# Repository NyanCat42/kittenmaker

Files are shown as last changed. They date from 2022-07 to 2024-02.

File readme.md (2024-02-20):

# kittenmaker

*kittenmaker* - an ESP32 based msla 3d printer

## YouTube video showcase 

Showcase video (https://www.youtube.com/watch?v=y37ohpzv8kI)

## Features 

- Web interface
- g-code parsing
- mid-print parameter updating
- magnetic, easily removable vat and printbed

kitten printed with the kittenmaker

## Hardware

- 3D printed body, vat, z-carriage

- 320x240 ili9341 TFT display (~0.14mm xy resolution)
- 28byj-48-5v stepper motor with uln2003 driver
- ESP32 development board
- 3W 405nm UV LED

- Various M3 and M2 hardware
- 3x7x3 bearings
- Body of a Bic crystal

## Software

Slicer [Chitubox 1.8 beta](https://www.chitubox.com/en/download/chitubox-free).

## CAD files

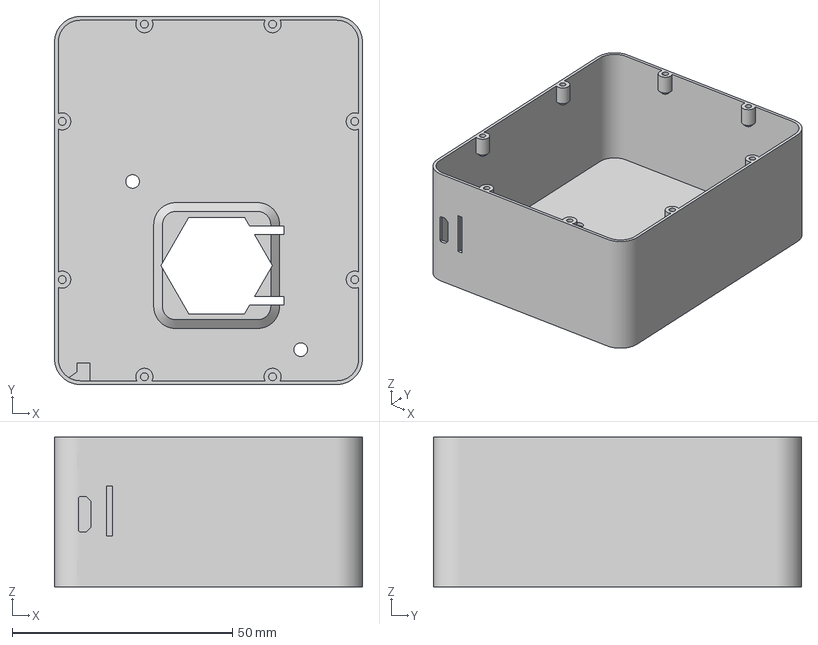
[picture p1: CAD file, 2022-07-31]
3d models/bottom (1).3mf
69.9 x 83.6 x 34.0 mm

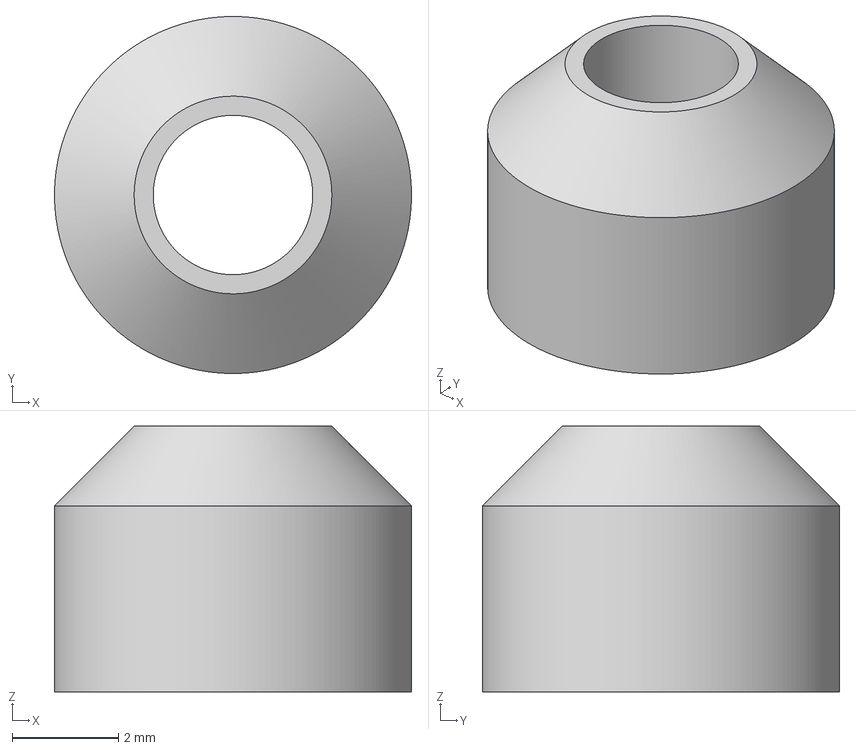
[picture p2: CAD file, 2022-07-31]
3d models/post.3mf
6.72 x 6.72 x 5.00 mm

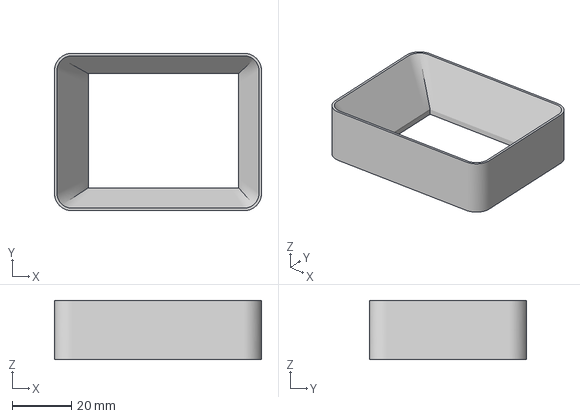
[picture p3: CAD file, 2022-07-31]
3d models/vat.3mf
69.9 x 53.2 x 20.0 mm

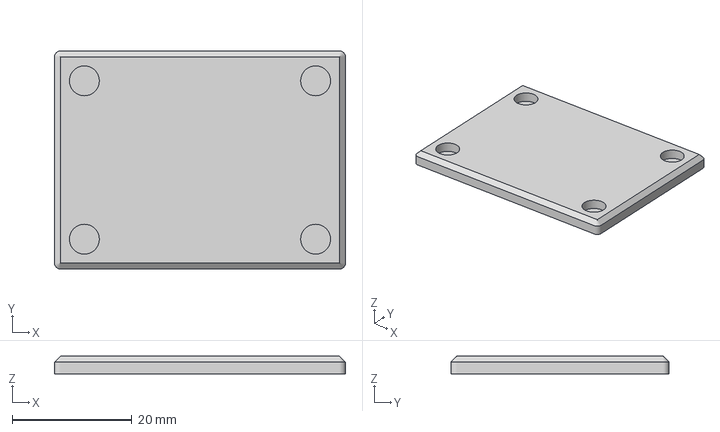
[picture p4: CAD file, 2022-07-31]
3d models/bed.3mf
48.7 x 36.5 x 3.00 mm

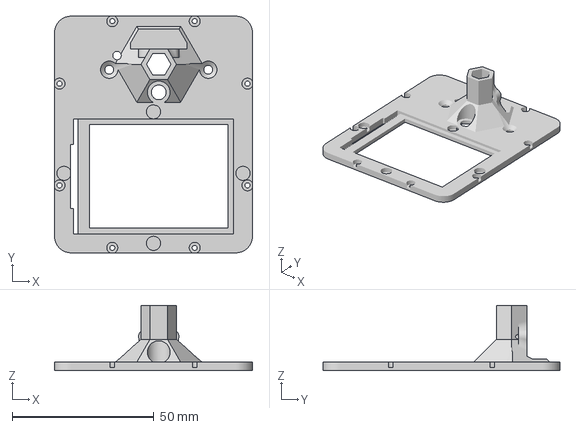
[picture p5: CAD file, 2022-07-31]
3d models/cover.3mf
69.9 x 83.6 x 23.0 mm

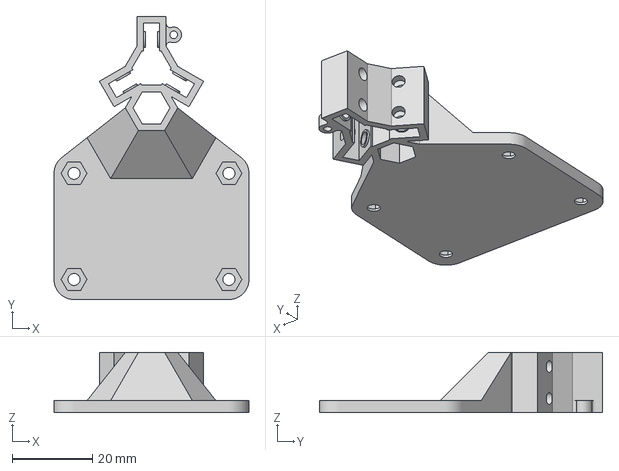
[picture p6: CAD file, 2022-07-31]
3d models/carriage.3mf
48.7 x 70.7 x 15.0 mm

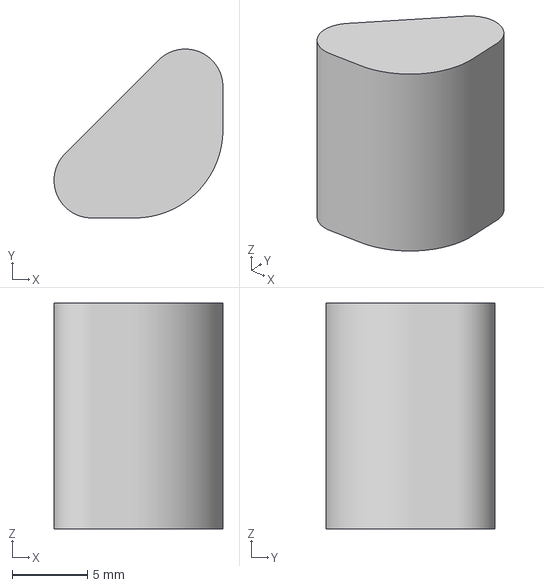
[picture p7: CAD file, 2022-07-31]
3d models/leg.3mf
11.2 x 11.2 x 15.0 mm

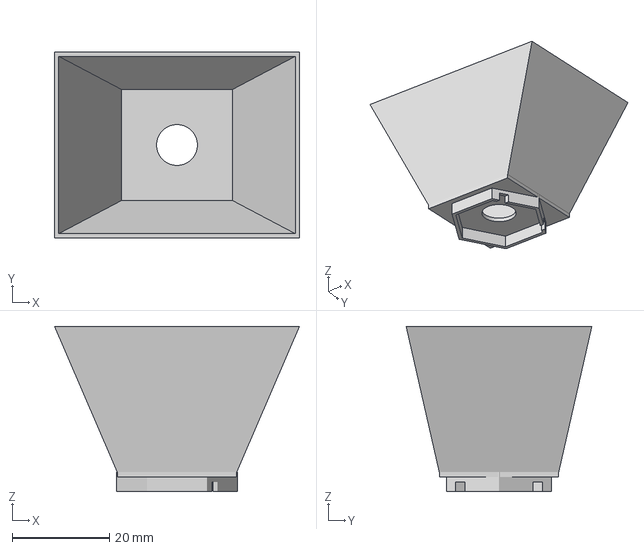
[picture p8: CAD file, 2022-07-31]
3d models/light_tunel.3mf
50.4 x 38.2 x 34.0 mm

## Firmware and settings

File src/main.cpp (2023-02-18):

#include <Arduino.h>
#include <WiFi.h>
#include <AsyncTCP.h>
#include <ESPAsyncWebServer.h>
#include "SPIFFS.h"
#include <Arduino_JSON.h>


#include <SPI.h>
#include <FS.h>
#include <SD.h>
#define FS_NO_GLOBALS

#include "setup_pins.h"
#include "wifi_ssid_password.h"

#include <GCodeParser.h>
GCodeParser GCode = GCodeParser();

#include <AccelStepper.h>
AccelStepper stepper1(8, stepper_pin_1, stepper_pin_3, stepper_pin_2, stepper_pin_4); // NOTE: The sequence 1-3-2-4 is required for proper sequencing of 28BYJ-48

#include <TFT_eSPI.h>
TFT_eSPI tft = TFT_eSPI();

#define USE_LINE_BUFFER
#include "support_functions.h"

int layerheight = 0;
int exposure_time = 0;
int bottom_exposure_time = 0;
int exposure_time_print;
int stepper_speed = 1000;
int stepper_accl = 1000;
int rise_height = 0;
int steps_per_layer;
float steps_per_um = 1.0189432; // or, to be more precise - 1.018943209876543209876543209876543209876543209876543209876543209876543209876543209876543209876543209876543209876543209876543209877
int layer = 1;
bool print_started = false;
bool calibrating = false;
bool raising = false;
int rise_height_steps = 0;
bool not_home = 1;
String filename;
int bottom_layer_count = 0;
int layercount;
int bottom_rise_height = 0;
int bottom_stepper_speed = 1000;
int layerPercent = 0;
unsigned long layerTimerStart, layerTimerFinish, layerTimerElapsed;
int printTime;
String printTimeHMS = "";

AsyncWebServer server(80);
AsyncWebSocket ws("/ws");

String message = "";
String inputValue1 = String(layerheight);
String inputValue2 = String(exposure_time);
String inputValue3 = String(bottom_exposure_time);
String inputValue4 = String(rise_height);
String inputValue5 = String(bottom_rise_height);

JSONVar inputValues;
String getInputValues(){

  inputValues["inputValue1"] = String(inputValue1);
  inputValues["inputValue2"] = String(inputValue2);
  inputValues["inputValue3"] = String(inputValue3);
  inputValues["inputValue4"] = String(inputValue4);
  inputValues["inputValue5"] = String(inputValue5);
  inputValues["fileName"] = filename;
  inputValues["estimatedTime"] = printTimeHMS;
  inputValues["progressBar"] = String("width: " + String(layerPercent) + "%;");
  String jsonString = JSON.stringify(inputValues);
  return jsonString;
}

void initFS() {
  if (!SPIFFS.begin()) {
    Serial.println("An error has occurred while mounting SPIFFS");
  }
  else{
   Serial.println("SPIFFS mounted successfully");
  }
}

void initWiFi() {
  WiFi.mode(WIFI_STA);
  WiFi.begin(ssid, password);
  Serial.print("Connecting to WiFi ..");
  while (WiFi.status() != WL_CONNECTED) {
    Serial.print('.');
    delay(1000);
  }
  Serial.println(WiFi.localIP());
}

void notifyClients(String inputValues) {
  ws.textAll(inputValues);
}

void handleWebSocketMessage(void *arg, uint8_t *data, size_t len) {
  AwsFrameInfo *info = (AwsFrameInfo*)arg;
  if (info->final && info->index == 0 && info->len == len && info->opcode == WS_TEXT) {
    data[len] = 0;
    message = (char*)data;
    if (message.indexOf("1s") >= 0) {
      inputValue1 = message.substring(2);
      layerheight = inputValue1.toInt();
      notifyClients(getInputValues());
    }
    if (message.indexOf("2s") >= 0) {
      inputValue2 = message.substring(2);
      exposure_time = inputValue2.toInt();
      notifyClients(getInputValues());
    }    
    if (message.indexOf("3s") >= 0) {
      inputValue3 = message.substring(2);
      bottom_exposure_time = inputValue3.toInt();
      notifyClients(getInputValues());
    }
    if (message.indexOf("4s") >= 0) {
      inputValue4 = message.substring(2);
      rise_height = inputValue4.toInt();
      notifyClients(getInputValues());
    }
    if (message.indexOf("5s") >= 0) {
      inputValue5 = message.substring(2);
      bottom_rise_height = inputValue5.toInt();
      notifyClients(getInputValues());
    }
    if (message.indexOf("6s") >= 0) {
      print_started = true;
      notifyClients(getInputValues());
    }
    if (message.indexOf("7s") >= 0) {
      print_started = false;
      calibrating = false;
      raising = false;
      tft.fillScreen(0);
      layer = 1;
      Serial.println("stop");
      notifyClients(getInputValues());
    }
    if (message.indexOf("8s") >= 0) {
      calibrating = true;
      Serial.println("home");
      notifyClients(getInputValues());
    }
    if (message.indexOf("9s") >= 0) {
      raising = true;
      Serial.println("raise");
      notifyClients(getInputValues());
    }
    if (strcmp((char*)data, "getValues") == 0) {
      notifyClients(getInputValues());
    }
  }
}
void onEvent(AsyncWebSocket *server, AsyncWebSocketClient *client, AwsEventType type, void *arg, uint8_t *data, size_t len) {
  switch (type) {
    case WS_EVT_CONNECT:
      Serial.printf("WebSocket client #%u connected from %s\n", client->id(), client->remoteIP().toString().c_str());
      break;
    case WS_EVT_DISCONNECT:
      Serial.printf("WebSocket client #%u disconnected\n", client->id());
      break;
    case WS_EVT_DATA:
      handleWebSocketMessage(arg, data, len);
      break;
    case WS_EVT_PONG:
    case WS_EVT_ERROR:
      break;
  }
}

void initWebSocket() {
  ws.onEvent(onEvent);
  server.addHandler(&ws);
}

void secToHMS(){
  int t, h, m, s;
  t = printTime;
  
  s = t % 60;
  t = (t - s)/60;
  m = t % 60;
  t = (t - m)/60;
  h = t;

  printTimeHMS = "Estimated print time: "+String(h)+":"+String(m)+":"+String(s);

  Serial.println(printTimeHMS);
}

void parseGcode() {
      File gCodeFile = SD.open("/run.gcode");
    if (gCodeFile)
    {
      int settingsLenght = 1;
      while (gCodeFile.available() && settingsLenght <= 27)
      {
        if (GCode.AddCharToLine(gCodeFile.read()))
        {
          GCode.ParseLine();
          GCode.RemoveCommentSeparators();
          if(settingsLenght == 8){
              layerheight = String(GCode.comments).substring(12).toFloat()*1000;
              Serial.println(layerheight);
          }if(settingsLenght == 15){
              exposure_time = String(GCode.comments).substring(19).toInt();
              Serial.println(exposure_time);
          }if(settingsLenght == 17){
              bottom_exposure_time = String(GCode.comments).substring(24).toInt();
              Serial.println(bottom_exposure_time);
          }if(settingsLenght == 19){
              rise_height = String(GCode.comments).substring(22).toInt();
              Serial.println(rise_height);
          }if(settingsLenght == 21){
              stepper_speed = String(GCode.comments).substring(21).toInt();
              Serial.println(stepper_speed);
          }if(settingsLenght == 1){
              filename = String(GCode.comments).substring(9);
              Serial.println(filename);
          }if(settingsLenght == 23){
              bottom_layer_count = String(GCode.comments).substring(17).toInt();
              Serial.println(bottom_layer_count);
          }if(settingsLenght == 25){
              layercount = String(GCode.comments).substring(11).toInt();
              Serial.println(layercount);
          }if(settingsLenght == 26){
              bottom_rise_height = String(GCode.comments).substring(22).toInt();
              Serial.println(bottom_rise_height);
          }if(settingsLenght == 27){
              bottom_stepper_speed = String(GCode.comments).substring(21).toInt();
              Serial.println(bottom_stepper_speed);
          }settingsLenght++;
        }
      }  
    }
  inputValue1 = String(layerheight);
  inputValue2 = String(exposure_time);
  inputValue3 = String(bottom_exposure_time);
  inputValue4 = String(rise_height);
  inputValue5 = String(bottom_rise_height);
  printTime = bottom_layer_count*bottom_rise_height*2+(layercount-bottom_layer_count)*rise_height*2+bottom_layer_count*bottom_exposure_time+(layercount-bottom_layer_count)*exposure_time;
  Serial.println(printTime);
  secToHMS();
}


void setup() {

  pinMode(Home_Switch, INPUT_PULLUP); // homing switch
  pinMode(UV_LED, OUTPUT);       // uv led driver (high is off)
  digitalWrite(UV_LED, 1);       // turn led off

  Serial.begin(115200);

  if (!SD.begin(SD_CS)) {
    Serial.println(F("SD.begin failed!"));
  }

  tft.begin();
  tft.setRotation(1);

  parseGcode();

  initFS();
  initWiFi();
  initWebSocket();
  
  server.on("/", HTTP_GET, [](AsyncWebServerRequest *request){
    request->send(SPIFFS, "/index.html", "text/html");
  });

  server.on("/preview", HTTP_GET, [](AsyncWebServerRequest *request){
    request->send(SD, "/preview.png", "image/png");
  });
  
  server.serveStatic("/", SPIFFS, "/");

  server.begin();

}

void loop() {

  stepper1.setAcceleration(stepper_accl);
  stepper1.setSpeed(stepper_speed);
  stepper1.setMaxSpeed(stepper_speed);
   
  not_home = digitalRead(Home_Switch);

  if(raising == true){
    Serial.println("raisung");
    stepper1.moveTo(stepper1.currentPosition() + steps_per_um * 20000);
    do {
     stepper1.run();
    } while (stepper1.distanceToGo() != 0 && raising == true);
    raising = false;
  }

  if(calibrating == true){
    Serial.println("calibrating");
    stepper1.moveTo(stepper1.currentPosition() - steps_per_um * 100000);
    do {
     stepper1.run();
     not_home = digitalRead(Home_Switch);
    } while (not_home == 1 && stepper1.distanceToGo() != 0 && calibrating == true);
      not_home = digitalRead(Home_Switch);
    if(not_home == 0){
      calibrating = false;
      stepper1.moveTo(0);
      stepper1.setCurrentPosition(0);
    }
  }

  if(print_started == true){

    Serial.println(printTimeHMS);

    String layerstr = String(layer);
    String layerfilename = "/"+layerstr+".png";
    const char* layerfilenameconst = layerfilename.c_str();
    setPngPosition(0, 0);
    load_file(SD, layerfilenameconst);

    if(layer <= bottom_layer_count){
      exposure_time_print = bottom_exposure_time;
    }else {
      exposure_time_print = exposure_time;
    }

    digitalWrite(UV_LED, 0);
    delay(exposure_time_print*1000);
    digitalWrite(UV_LED, 1);

    steps_per_layer = steps_per_um * layerheight + 0.5;
    if(layer <= bottom_layer_count){
      rise_height_steps = bottom_rise_height * 1000 * steps_per_um;
      stepper1.setSpeed(bottom_stepper_speed);
      stepper1.setMaxSpeed(bottom_stepper_speed);
    }else {
      rise_height_steps = rise_height * 1000 * steps_per_um;
      stepper1.setSpeed(stepper_speed);
      stepper1.setMaxSpeed(stepper_speed);
    }


    layerTimerStart=millis();

    stepper1.moveTo(stepper1.currentPosition() + steps_per_layer + rise_height_steps);

    do {
      stepper1.run();
    } while (stepper1.distanceToGo() != 0);

    stepper1.moveTo(stepper1.currentPosition()-rise_height_steps);

    do {
      stepper1.run();
    } while (stepper1.distanceToGo() != 0);

    layerTimerFinish=millis();
    layerTimerElapsed=layerTimerFinish-layerTimerStart;
    Serial.println(layerTimerElapsed);

    if(layer <= bottom_layer_count){
      printTime = (bottom_layer_count-layer)*layerTimerElapsed/1000+(layercount-bottom_layer_count)*rise_height*(layerTimerElapsed/1000/bottom_rise_height)+(bottom_layer_count-layer)*bottom_exposure_time+(layercount-bottom_layer_count)*exposure_time;
    }else {
      printTime = (layercount-layer)*layerTimerElapsed/1000+(layercount-layer)*exposure_time;
    }
    Serial.println(printTime);
    secToHMS();

    layer = layer + 1;
    layerPercent = layer*100/layercount;
      
    if (layercount < layer) {
      print_started = false;
      tft.fillScreen(0);
      layer = 1;
      raising = true;
    }
     
  }

  ws.cleanupClients();
}

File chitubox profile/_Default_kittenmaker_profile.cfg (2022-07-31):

@@kittenmaker@@__resin:
@@kittenmaker@@antiAliasLevel:8
@@kittenmaker@@bAntiAliasLevelEditable:1
@@kittenmaker@@bAntiAliasing:1
@@kittenmaker@@bBottomInnerOutterCircleOffsetEnable:0
@@kittenmaker@@bBuildAreaOffsetEnable:0
@@kittenmaker@@bDisplayCorrectEnable:0
@@kittenmaker@@bImageBlur:0
@@kittenmaker@@bImageBlurPixelEditable:1
@@kittenmaker@@bImageMask:0
@@kittenmaker@@bInnerOutterCircleOffsetEnable:0
@@kittenmaker@@bLockXYSizeRatio:1
@@kittenmaker@@bSurfaceRoughEditable:0
@@kittenmaker@@bottomEdgeExposureMM:0
@@kittenmaker@@bottomEdgeExposureTimeS:4
@@kittenmaker@@bottomExposureTimeStrategy:0
@@kittenmaker@@bottomInnerCircleOffset:0
@@kittenmaker@@bottomLayerCount:5
@@kittenmaker@@bottomLayerDropHeight2:
@@kittenmaker@@bottomLayerDropSpeed:
@@kittenmaker@@bottomLayerDropSpeed2:
@@kittenmaker@@bottomLayerExposureTime:45
@@kittenmaker@@bottomLayerLiftHeight:5
@@kittenmaker@@bottomLayerLiftHeight2:0
@@kittenmaker@@bottomLayerLiftSpeed:500
@@kittenmaker@@bottomLayerLiftSpeed2:65
@@kittenmaker@@bottomLightIntensityPWM:255
@@kittenmaker@@bottomLightOffTime:0
@@kittenmaker@@bottomOutterCircleOffset:0
@@kittenmaker@@bottomRestTimeAfterLift:0
@@kittenmaker@@bottomRestTimeAfterRetract:0
@@kittenmaker@@bottomRestTimeBeforeLift:0
@@kittenmaker@@buildAreaOffsetBottom:0
@@kittenmaker@@buildAreaOffsetLeft:0
@@kittenmaker@@buildAreaOffsetRight:0
@@kittenmaker@@buildAreaOffsetTop:0
@@kittenmaker@@circleParityDifference:0
@@kittenmaker@@currProfileName:kittenmaker
@@kittenmaker@@displayCorrectLeftBottomX:0
@@kittenmaker@@displayCorrectLeftBottomY:0
@@kittenmaker@@displayCorrectLeftTopX:0
@@kittenmaker@@displayCorrectLeftTopY:0
@@kittenmaker@@displayCorrectRightBottomX:0
@@kittenmaker@@displayCorrectRightBottomY:0
@@kittenmaker@@displayCorrectRightTopX:0
@@kittenmaker@@displayCorrectRightTopY:0
@@kittenmaker@@edgeExposureMM:0
@@kittenmaker@@edgeExposureTimeS:4
@@kittenmaker@@endGcode:
@@kittenmaker@@fillDensity:30
@@kittenmaker@@fillPattern:None
@@kittenmaker@@imageBlurPixel:2
@@kittenmaker@@imageMaskFile:
@@kittenmaker@@innerCircleOffset:0
@@kittenmaker@@layerGcode:
@@kittenmaker@@layerHeight:0.1
@@kittenmaker@@lightOffTime:0
@@kittenmaker@@machineDepth:33.839999999999996
@@kittenmaker@@machineHeight:70
@@kittenmaker@@machineType:default
@@kittenmaker@@machineWidth:45.12
@@kittenmaker@@maskGrayScaleUnit:4
@@kittenmaker@@maxGreyLevel:255
@@kittenmaker@@minGreyLevel:0
@@kittenmaker@@normalExposureTime:15
@@kittenmaker@@normalLayerDropHeight2:0
@@kittenmaker@@normalLayerDropSpeed:0
@@kittenmaker@@normalLayerDropSpeed2:0
@@kittenmaker@@normalLayerLiftHeight:3
@@kittenmaker@@normalLayerLiftHeight2:0
@@kittenmaker@@normalLayerLiftSpeed:1000
@@kittenmaker@@normalLayerLiftSpeed2:65
@@kittenmaker@@normalLightIntensityPWM:255
@@kittenmaker@@normalRestTimeAfterLift:0
@@kittenmaker@@normalRestTimeAfterRetract:0
@@kittenmaker@@normalRestTimeBeforeLift:0
@@kittenmaker@@outterCircleOffset:0
@@kittenmaker@@projectType:LCD_mirror
@@kittenmaker@@resinDensity:0
@@kittenmaker@@resinPrice:0
@@kittenmaker@@resinUnit:€/L
@@kittenmaker@@resolutionX:320
@@kittenmaker@@resolutionY:240
@@kittenmaker@@shellThickness:1
@@kittenmaker@@sliceExportPart:0
@@kittenmaker@@startGcode:\n
@@kittenmaker@@surfaceRoughLevel:1
@@kittenmaker@@transitionLayerCount:0
@@kittenmaker@@transitionLayerType:0
@@kittenmaker@@zSlowUpDistance:0
__resin:
antiAliasLevel:8
bAntiAliasLevelEditable:1
bAntiAliasing:1
bBottomInnerOutterCircleOffsetEnable:0
bBuildAreaOffsetEnable:0
bDisplayCorrectEnable:0
bImageBlur:0
bImageBlurPixelEditable:1
bImageMask:0
bInnerOutterCircleOffsetEnable:0
bLockXYSizeRatio:1
bSurfaceRoughEditable:0
bottomEdgeExposureMM:0
bottomEdgeExposureTimeS:4
bottomExposureTimeStrategy:0
bottomInnerCircleOffset:0
bottomLayerCount:5
bottomLayerDropHeight2:
bottomLayerDropSpeed:
bottomLayerDropSpeed2:
bottomLayerExposureTime:45
bottomLayerLiftHeight:5
bottomLayerLiftHeight2:0
bottomLayerLiftSpeed:500
bottomLayerLiftSpeed2:65
bottomLightIntensityPWM:255
bottomLightOffTime:0
bottomOutterCircleOffset:0
bottomRestTimeAfterLift:0
bottomRestTimeAfterRetract:0
bottomRestTimeBeforeLift:0
buildAreaOffsetBottom:0
buildAreaOffsetLeft:0
buildAreaOffsetRight:0
buildAreaOffsetTop:0
circleParityDifference:0
currProfile:kittenmaker
displayCorrectLeftBottomX:0
displayCorrectLeftBottomY:0
displayCorrectLeftTopX:0
displayCorrectLeftTopY:0
displayCorrectRightBottomX:0
displayCorrectRightBottomY:0
displayCorrectRightTopX:0
displayCorrectRightTopY:0
edgeExposureMM:0
edgeExposureTimeS:4
endGcode:
fillDensity:30
fillPattern:None
imageBlurPixel:2
imageMaskFile:
innerCircleOffset:0
layerGcode:
layerHeight:0.1
lightOffTime:0
machineDepth:33.839999999999996
machineHeight:70
machineType:default
machineWidth:45.12
maskGrayScaleUnit:4
maxGreyLevel:255
minGreyLevel:0
normalExposureTime:15
normalLayerDropHeight2:0
normalLayerDropSpeed:0
normalLayerDropSpeed2:0
normalLayerLiftHeight:3
normalLayerLiftHeight2:0
normalLayerLiftSpeed:1000
normalLayerLiftSpeed2:65
normalLightIntensityPWM:255
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

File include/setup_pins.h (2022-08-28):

#define SD_CS   1

#define UV_LED   37

#define Home_Switch   39

#define stepper_pin_4 16
#define stepper_pin_3 18
#define stepper_pin_2 33
#define stepper_pin_1 35

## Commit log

2022-02-18 revised vat, added screw holes, added roll axis bearings
    [fep seal for vat v2.3mf, head.3mf, vat v2.3mf]
2022-02-18 moved pin asignment to seperate file
2022-07-26 switched from jpeg to png
2022-07-31 V2, uses a bic crystal and as a linear rail
    [bed.3mf, bottom (1).3mf, carriage.3mf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]
2022-07-31 added chitubox profile
    [_Default_kittenmaker_profile.cfg]
2022-08-26 moved to ESP32-S2 board
2023-02-14 steps per um adjusted for 4mm lead screw
2023-02-15 Revert "Merge branch 'main' of https://github.com/NyanCat42/kittenmaker"
    This reverts commit fb6a4a3f91de5e1710a7333001582975ea9b33b8, reversing
    changes made to c4aae8870d5d6346056c4f30835e896fc77867ad.
    [main.cpp]
2023-02-15 Revert "Revert "Merge branch 'main' of https://github.com/NyanCat42/kittenmaker""
    This reverts commit b8a8a8863365199c9840cfa0063241726d64e460.
    [main.cpp]
2023-02-15 reverting the revert of the revert and the things i wanted to revert
    This reverts commit 97b772739b0cce02b67bcab62022ab0866158f8b.
    [main.cpp]
2023-02-15 reverting the revert of the revert and the things i wanted to revert
    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
    [main.cpp]
2023-02-15 Revert accidental changes and the revert of the revert of the revert
    This reverts commit a279bad8abd2853c3d11642e1363d17d632cbe11.
    [main.cpp]
2023-02-18 initial print time estimate improvement
